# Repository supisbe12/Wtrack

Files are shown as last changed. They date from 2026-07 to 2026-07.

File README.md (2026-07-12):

# Wtrack
Wtrack — a multi-network location tracker device

Wtrack is a tracker with a combination of Apple Find My, Hubble (terrestrial + satellite), GPS, and BLE proximity detection on one barebones PCB (no enclosure) which goes inside your wallet.
I want it to be barebone because I wanted to be able to see the actual PCB because it looks cool ,But I am planning to add a layer acrylic spray that I already have available to prevent water from affecting the board.

---
Schematic



PCB



3D view



Battery Cap



---
Bill Of Materials: https://docs.google.com/spreadsheets/d/1D9NDHI8oiGVwoLBUYLz9mFe_7Vkk39w_oN8q6zxxxLU/edit?usp=sharing

Bill of materials (CSV): https://github.com/supisbe12/Wtrack/blob/main/BOM.csv

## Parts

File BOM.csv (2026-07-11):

Reference | Qty | Value | DNP | Exclude from BOM | Exclude from Board | Footprint | Datasheet
B1 | 1 | CR2032-BS-6-1 |  |  |  | easyeda:BAT-TH_CR2032-BS-6-1 | https://lcsc.com/product-detail/Battery-Holders-Clips-Contacts_Button-battery-holder-CR2032_C70377.html
C1,C2 | 2 | 12pF NP0 ±2%, 0402 |  |  |  | easyeda:C0402 | https://lcsc.com/product-detail/Multilayer-Ceramic-Capacitors-MLCC-SMD-SMT_12pF-120-5-50V_C1547.html
C3 | 1 | 0.3pF |  |  |  | easyeda:C0201 | https://lcsc.com/product-detail/Multilayer-Ceramic-Capacitors-MLCC-SMD-SMT_muRata_GRM0335C1ER30BA01D_0-3pF-R30-0-1pF-25V_C88909.html
C4 | 1 | 1.0pF NP0 ±5%, 0402 |  |  |  | easyeda:C0402 | https://lcsc.com/product-detail/Multilayer-Ceramic-Capacitors-MLCC-SMD-SMT_100pF-101-5-50V_C1546.html
C5 | 1 | 100nF X7R ±10%, 0402 |  |  |  | easyeda:C0402 | https://lcsc.com/product-detail/Multilayer-Ceramic-Capacitors-MLCC-SMD-SMT_SAMSUNG_CL05B104KO5NNNC_100nF-104-10-16V_C1525.html
C6 | 1 | 4.7uF X7R ±10%, 0603 |  |  |  | Capacitor_SMD:C_0603_1608Metric | https://search.murata.co.jp/Ceramy/image/img/A01X/G101/ENG/GRM188Z71A475KE15-01A.pdf
C7,C8,C12 | 3 | 100pF NP0 ±5%, 0402 |  |  |  | easyeda:C0402 | https://lcsc.com/product-detail/Multilayer-Ceramic-Capacitors-MLCC-SMD-SMT_100pF-101-5-50V_C1546.html
C9 | 1 | 820pF NP0 ±5%, 0402 |  |  |  | easyeda:C0402 | https://lcsc.com/product-detail/Multilayer-Ceramic-Capacitors-MLCC-SMD-SMT_SAMSUNG_CL05B104KO5NNNC_100nF-104-10-16V_C1525.html
C10 | 1 | KR-5R5C155-R |  |  |  | KR5R5C155R | https://componentsearchengine.com/Datasheets/2/KR-5R5C155-R.pdf
C14,C15 | 2 | 1.0µF X7R ±10%, 0603 |  |  |  | Capacitor_SMD:C_0603_1608Metric | https://search.murata.co.jp/Ceramy/image/img/A01X/G101/ENG/GRM188Z71A475KE15-01A.pdf
C16 | 1 | 4.7nF X7R ±10% |  |  |  | easyeda:C0402 | https://lcsc.com/product-detail/Multilayer-Ceramic-Capacitors-MLCC-SMD-SMT_SAMSUNG_CL05B104KO5NNNC_100nF-104-10-16V_C1525.html
C19 | 1 | 10uF |  |  |  | easyeda:C0603 | https://lcsc.com/product-detail/Multilayer-Ceramic-Capacitors-MLCC-SMD-SMT_SAMSUNG_CL10A106KP8NNNC_10uF-106-10-10V_C19702.html
FL1 | 1 | 2450LP14A100T |  |  |  | easyeda:FILTER-SMD_0603-6P-L1.6-W0.8_2450LP14A100T | https://www.lcsc.com/datasheet/C3155782.pdf
IC1 | 1 | RFX2401C |  |  |  | QFN50P300X300X60-17N-D
L1 | 1 | 4.7nH ±5%, 0402 |  |  |  | easyeda:L0402 | https://lcsc.com/product-detail/Inductors-SMD_muRata_LQP15MN4N7B02D_4-7nH-0-1nH_C23769.html
L2 | 1 | 10µH, IDC≥50mA, 0603 |  |  |  | easyeda:L0603 | https://lcsc.com/product-detail/Inductors-SMD_10uH-10_C1035.html
L3 | 1 | 47nH |  |  |  | easyeda:L0402 | https://lcsc.com/product-detail/Inductors-SMD_muRata_LQW15AN47NG00D_LQW15AN47NG00D_C22334.html
L4 | 1 | 10µH, IDC≥80mA, 0603 |  |  |  | easyeda:L0603 | https://lcsc.com/product-detail/Inductors-SMD_10uH-10_C1035.html
L5 | 1 | 3.9nH ±5%, 0402 |  |  |  | easyeda:L0402 | https://lcsc.com/product-detail/Inductors-SMD_muRata_LQG15HS2N2S02D_2-2nH-0-3nH_C86061.html
L7 | 1 | Bluetooth Antenna |  |  |  | easyeda:ANT-SMD_3P-L3.1-W1.6_ANT3216A063R2400A | https://lcsc.com/product-detail/New-Arrivals_YAGEO-ANT3216A063R2400A_C412135.html
R1 | 1 | 100Ω |  |  |  | Resistor_SMD:R_0402_1005Metric
SC2 | 1 | 3F,2.7V |  |  |  | Capacitor_THT:CP_Radial_D10.0mm_P5.00mm
U1 | 1 | GPS |  |  |  | easyeda:ANT-SMD_L10.0-W3.0 | https://lcsc.com/product-detail/Others_Rainsun-microwave-Tech-GPS1003_C239243.html
U2 | 1 | ATGM336H-5N31 |  |  |  | easyeda:GPSM-SMD_ATGM336H-TR | https://lcsc.com/product-detail/GSM-GPRS-GPS-Modules_ATGM336H-5N-3X_C90770.html
U4 | 1 | NRF52840-QIAA-R |  |  |  | easyeda:AQFN-73_L7.0-W7.0-P0.50-BL-EP4.8 | https://lcsc.com/product-detail/Others_Nordic-Semicon_NRF52840-QIAA-R_Nordic-Semicon-NRF52840-QIAA-R_C190794.html
X1 | 1 | NX2016SA-32MHZ-STD-CZS-5 |  |  |  | easyeda:OSC-SMD_4P-L2.0-W1.6-BL | https://www.lcsc.com/datasheet/C843260.pdf

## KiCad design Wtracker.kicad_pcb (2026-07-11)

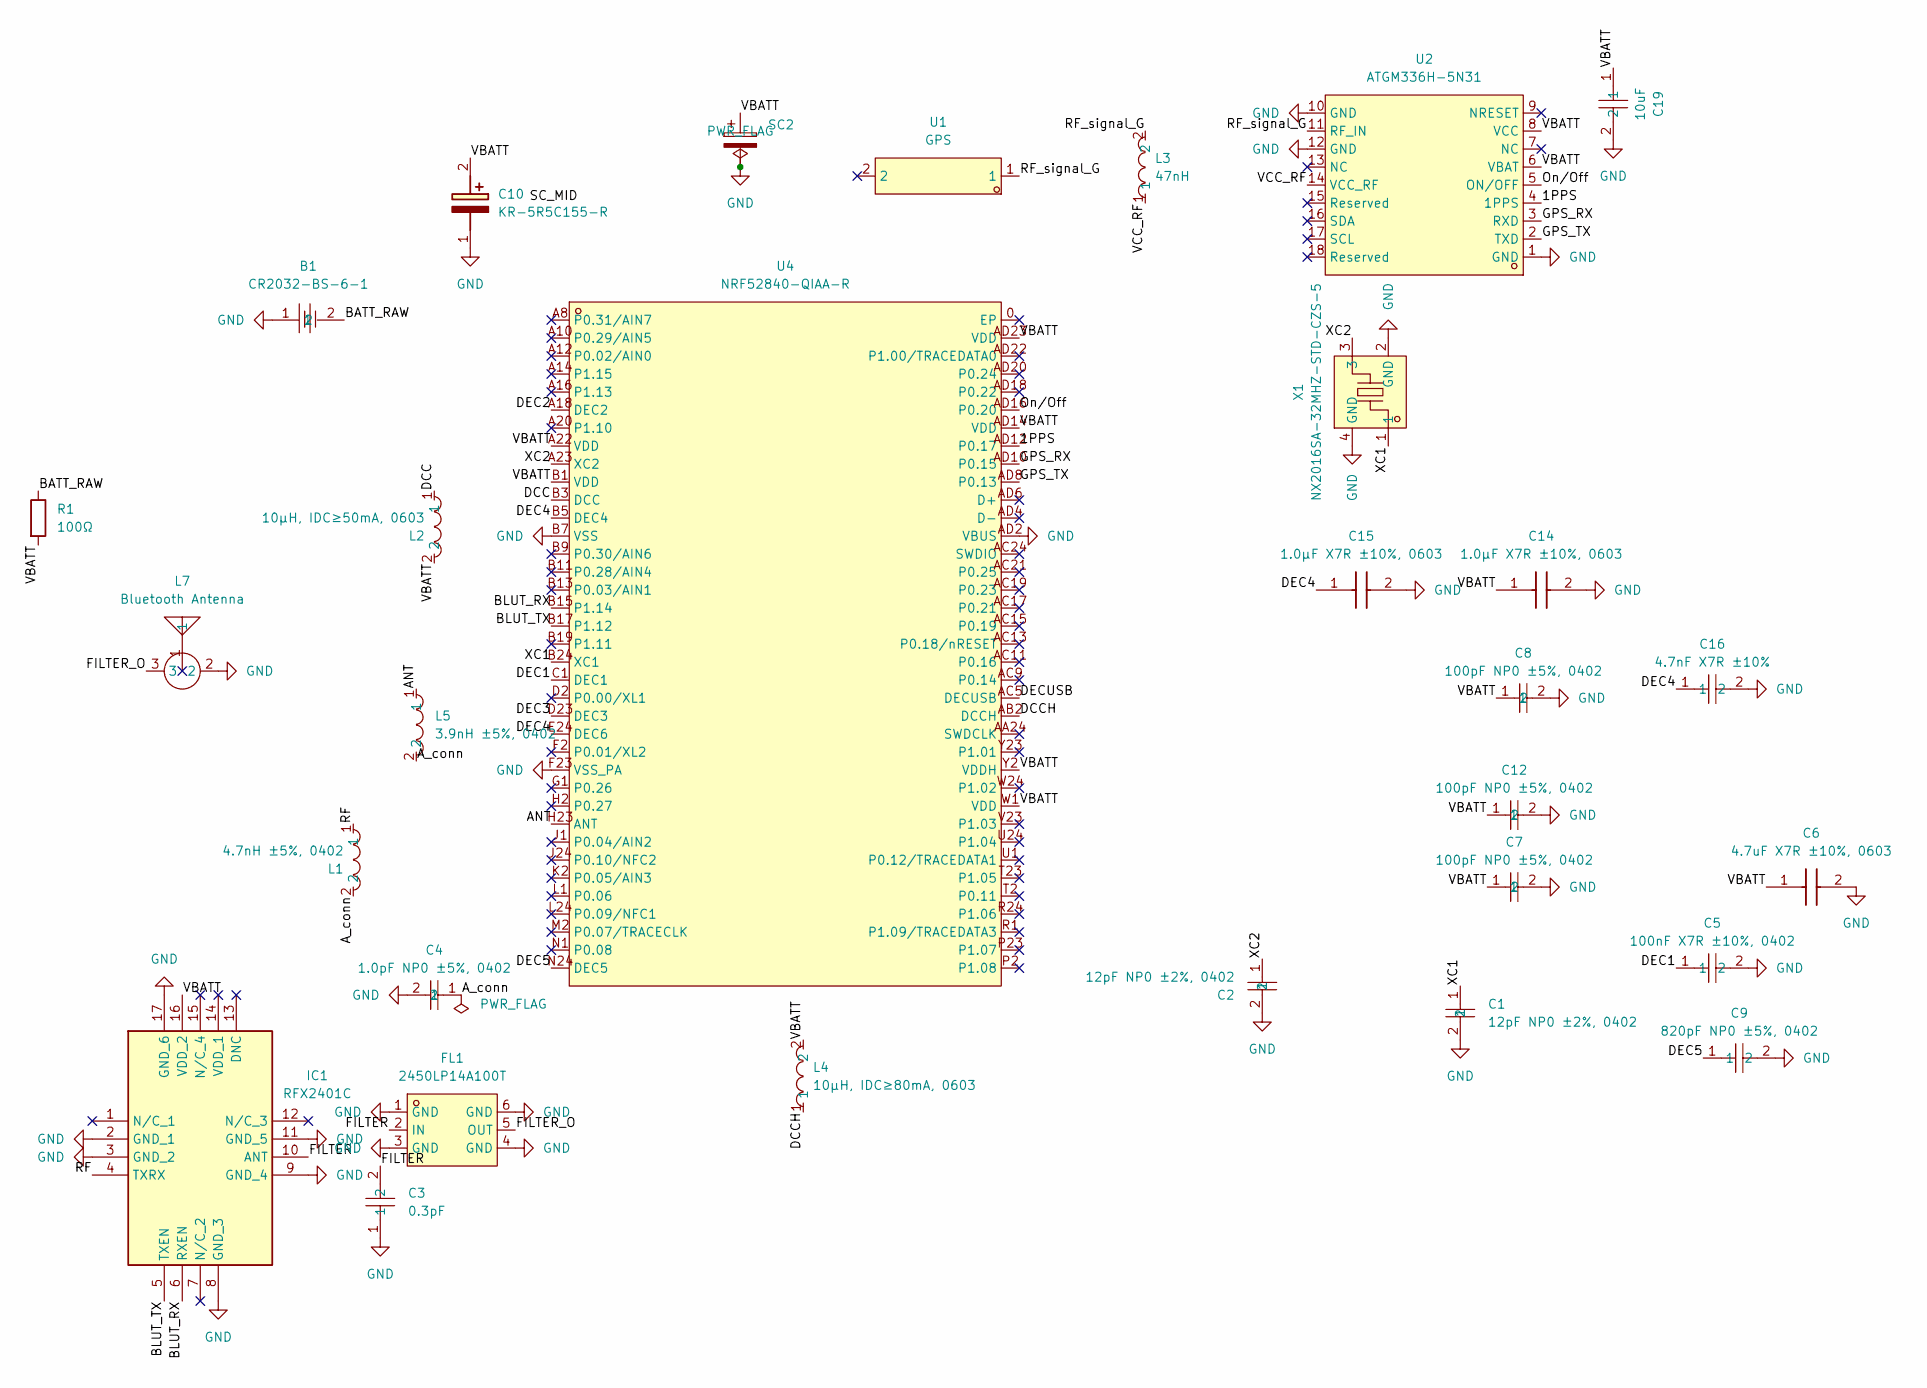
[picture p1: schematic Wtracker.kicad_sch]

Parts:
B1: CR2032-BS-6-1; BAT-TH_CR2032-BS-6-1; MPN CR2032-BS-6-1; LCSC Part C70377
C1, C2: 12pF NP0 ±2%, 0402; C0402; MPN 0402CG120J500NT; LCSC Part C1547
C3: 0.3pF; C0201; MPN GRM0335C1ER30BA01D; LCSC Part C88909
C4: 1.0pF NP0 ±5%, 0402; C0402; MPN 0402CG101J500NT; LCSC Part C1546
C5: 100nF X7R ±10%, 0402; C0402; MPN CL05B104KO5NNNC; LCSC Part C1525
C6: 4.7uF X7R ±10%, 0603; C_0603_1608Metric; Mouser Part Number 81-GRM188Z71A475KE5D
C7, C8, C12: 100pF NP0 ±5%, 0402; C0402; MPN 0402CG101J500NT; LCSC Part C1546
C9: 820pF NP0 ±5%, 0402; C0402; MPN CL05B104KO5NNNC; LCSC Part C1525
C10: KR-5R5C155-R; KR5R5C155R; Mouser Part Number 504-KR-5R5C155-R
C14, C15: 1.0µF X7R ±10%, 0603; C_0603_1608Metric; Mouser Part Number 81-GRM188Z71A475KE5D
C16: 4.7nF X7R ±10%; C0402; MPN CL05B104KO5NNNC; LCSC Part C1525
C19: 10uF; C0603; MPN CL10A106KP8NNNC; LCSC Part C19702
FL1: 2450LP14A100T; FILTER-SMD_0603-6P-L1.6-W0.8_2450LP14A100T; MPN 2450LP14A100T; LCSC Part C3155782
IC1: RFX2401C; QFN50P300X300X60-17N-D; Mouser Part Number 477-RFX2401C
L1: 4.7nH ±5%, 0402; L0402; MPN LQP15MN4N7B02D; LCSC Part C23769
L2: 10µH, IDC≥50mA, 0603; L0603; MPN SDFL1608S100KTF; LCSC Part C1035
L3: 47nH; L0402; MPN LQW15AN47NG00D; LCSC Part C22334
L4: 10µH, IDC≥80mA, 0603; L0603; MPN SDFL1608S100KTF; LCSC Part C1035
L5: 3.9nH ±5%, 0402; L0402; MPN LQG15HS2N2S02D; LCSC Part C86061
L7: Bluetooth Antenna; ANT-SMD_3P-L3.1-W1.6_ANT3216A063R2400A; MPN ANT3216A063R2400A; LCSC Part C412135
R1: 100Ω; R_0402_1005Metric
SC2: 3F,2.7V; CP_Radial_D10.0mm_P5.00mm
U1: GPS; ANT-SMD_L10.0-W3.0; MPN GPS1003; LCSC Part C239243
U2: ATGM336H-5N31; GPSM-SMD_ATGM336H-TR; MPN ATGM336H-5N31; LCSC Part C90770
U4: NRF52840-QIAA-R; AQFN-73_L7.0-W7.0-P0.50-BL-EP4.8; MPN NRF52840-QIAA-R; LCSC Part C190794
X1: NX2016SA-32MHZ-STD-CZS-5; OSC-SMD_4P-L2.0-W1.6-BL; MPN NX2016SA-32MHZ-STD-CZS-5; LCSC Part C843260

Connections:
/1PPS: U2.4 (1PPS), U4.AD12 (P0.17)
/ANT: L5.1, U4.H23 (ANT)
/A_conn: C4.1, L1.2, L5.2
/BATT_RAW: B1.2, R1.1
/BLUT_RX: IC1.6 (RXEN), U4.B15 (P1.14)
/BLUT_TX: IC1.5 (TXEN), U4.B17 (P1.12)
/DCC: L2.1, U4.B3 (DCC)
/DCCH: L4.1, U4.AB2 (DCCH)
/DEC1: C5.1, U4.C1 (DEC1)
/DEC2: U4.A18 (DEC2)
/DEC3: U4.D23 (DEC3)
/DEC4: C15.1, C16.1, U4.B5 (DEC4), U4.E24 (DEC6)
/DEC5: C9.1, U4.N24 (DEC5)
/DECUSB: U4.AC5 (DECUSB)
/FILTER: C3.2, FL1.2 (IN), IC1.10 (ANT)
/FILTER_O: FL1.5 (OUT), L7.3
/GPS_RX: U2.3 (RXD), U4.AD10 (P0.15)
/GPS_TX: U2.2 (TXD), U4.AD8 (P0.13)
/On/Off: U2.5 (ON/OFF), U4.AD16 (P0.20)
/RF: IC1.4 (TXRX), L1.1
/RF_signal_G: L3.2, U1.1 (1_1), U2.11 (RF_IN)
/VBATT: C6.1, C7.1, C8.1, C10.2 (+), C12.1, C14.1, C19.1, IC1.16 (VDD_2), L2.2, L4.2, R1.2, SC2.1, U2.6 (VBAT), U2.8 (VCC), U4.A22 (VDD), U4.AD14 (VDD), U4.AD23 (VDD), U4.B1 (VDD), U4.W1 (VDD), U4.Y2 (VDDH)
/VCC_RF: L3.1, U2.14 (VCC_RF)
/XC1: C1.1, U4.B24 (XC1), X1.1
/XC2: C2.1, U4.A23 (XC2), X1.3
GND: B1.1, C1.2, C2.2, C3.1, C4.2, C5.2, C6.2, C7.2, C8.2, C9.2, C10.1 (-), C12.2, C14.2, C15.2, C16.2, C19.2, FL1.1 (GND), FL1.3 (GND), FL1.4 (GND), FL1.6 (GND), IC1.2 (GND_1), IC1.3 (GND_2), IC1.8 (GND_3), IC1.9 (GND_4), IC1.11 (GND_5), IC1.17 (GND_6), L7.2, SC2.2, U2.1 (GND), U2.10 (GND), U2.12 (GND), U4.AD2 (VBUS), U4.B7 (VSS), U4.F23 (VSS_PA), X1.2 (GND), X1.4 (GND)

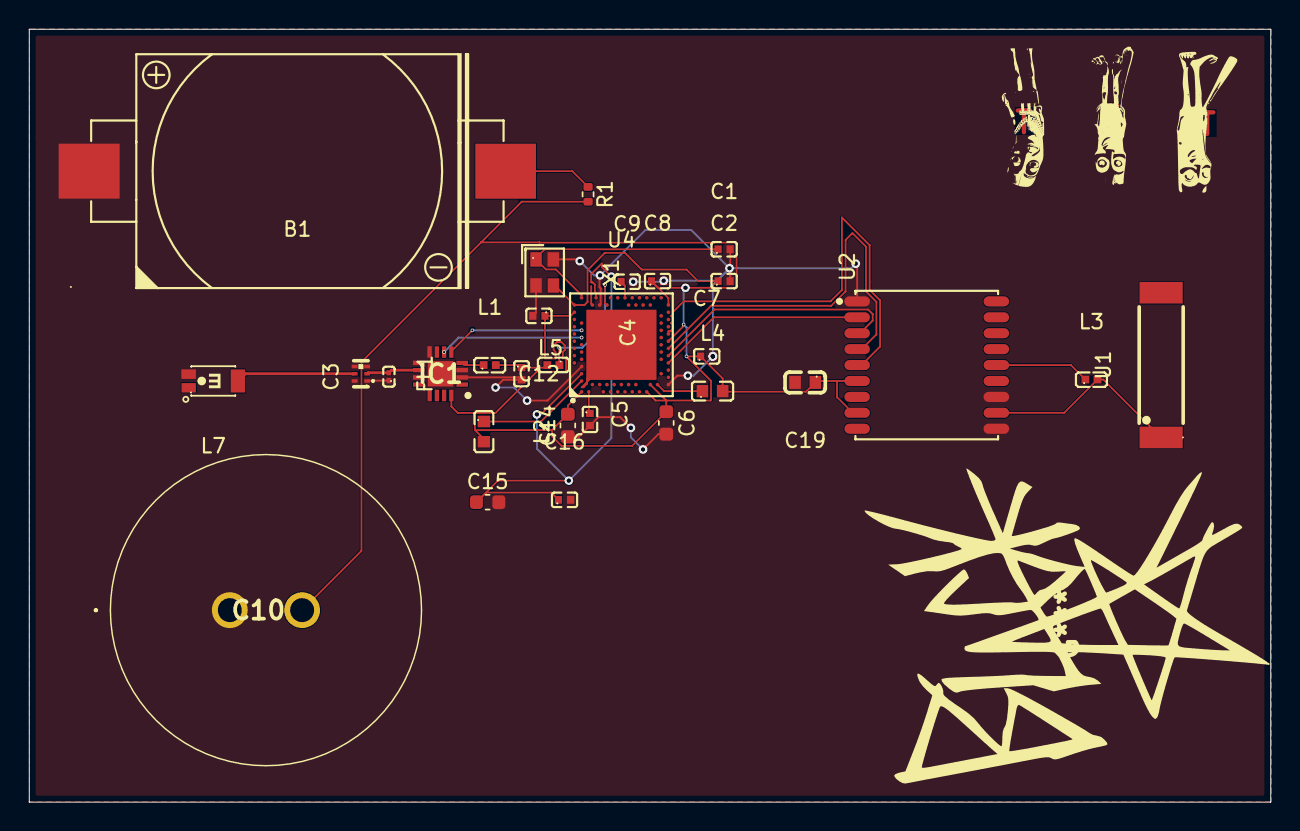
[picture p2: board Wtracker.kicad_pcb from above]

Board: 2 copper layers, 85.8 x 53.4 mm, 32 parts (0 on the bottom side), 23 nets.

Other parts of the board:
T: LOGO
T#2, T#3: LOGO

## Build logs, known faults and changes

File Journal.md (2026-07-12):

# Total time : 25 hours
**_Day 1_** - Searched for parts to plan out the schematic for this project - **5 hours**

I spent a lot of time to find out the exact footprints that I needed for each part of the schematic like capacitors, inductors, and antennas and many of the other parts.
It was difficult because I had to choose the exact needs of every part by using the datasheets.
I also spent a lot of time trying to figure out the problem that I had with importing symbol and footprints straight for LSCS or JLPCB using the ImpartGUI. This part took me like 2 hours and afterwards I asked a friend to help me and he introduced me to another plugin that allowed me to do
the same thing and it actually worked this time.



**_Day 2_** - Searched for Datasheets to connect schematics together - **7 hours**

Learned a lot about datasheets today and how to read them. It was really hard to figure out what some of the labels meant but google explained it well



Then I learned how to connect Antennas together and it was quite complicated with the usage of a lot of back and forth of capacitors and inductors which I didn't understand why then I researched it. which is required because to match the frequency.
Also learned that Antennas sometimes have different modes like active and passive.



Also got the board wrong yesterday so had to find a new one.



Schematic kinda messy gonna organize it tommorrow.

**_Day 3_** - Set up Kicad and easy EDA on my computer and finished schematics- **2 hours**

It took me a long time to setup kicad and all of the imports and file path right but when I finally got it working I was able to finish connecting the bluetooth harmonic filter and everything on that track.



It is still very messy I am going to clean it up soon when i get motivation.

**_Day 4_** - Fixed Footprints, Started PCB and wiring- **6 hours**

I had to add my old footprints which was on my computer and moved it on over to my laptop So I had to refind the footprint for some of the older parts that I placed.



After that, I was organizing the location of the hardware until I found it really hard to wire the NRF52840-QIAA-R because of it's extremely small pads.



It wasn't fitting the JLPCB standard and I decided to stop for the day and ask for help on slack and try again tomorrow.
I learned about some new stuff like impedance and stub routing/trace and new constraints that JLPCB have.

**_Day 5_** - Finished PCB- **5 hours**
I explored more options for JLPCB production and decided to use the smallest possible Vias that is allowed by JLPCB to wire the NRF. After that I just finished wiring everything based on my schematic while i did get a little confused at some point but it was pretty smooth sailing.

I learned a lot about the placements of antennas and everything and how they needed to be seperated and different copper

**_Day 6_** - Finished PCB- **2 hours**
Changed the PCB and researched a thinner and stronger capacitor to fit the thin look i'm looking for. updated schematic and BOM for review



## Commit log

2026-07-04 Force remove .history from tracking
    [Wtracker.kicad_pcb, Wtracker.kicad_sch]
2026-07-05 worked on antenna of pcb
    [GPSmod.kicad_sch, Wtracker.kicad_sch]
2026-07-05 added the GPS and finished Bluetooth antennas
    [GPSmod.kicad_sch, Wtracker.kicad_sch]
2026-07-05 Add journal entries for project progress
    Documented progress on project schematics and datasheets over two days, including challenges faced and solutions found.
2026-07-08 Revise journal with new entries and images
    Updated journal entries with new learnings about antennas, Kicad setup, and PCB design challenges. Added images and organized content for clarity.
2026-07-09 updated pcb and schematic
    [Wtracker.csv, Wtracker.kicad_pcb, Wtracker.kicad_sch]
2026-07-09 Add Bill Of Materials link to README
    Updated the README to include a link to the Bill Of Materials.
2026-07-11 Replace images in README.md
    Updated images in the README for schematic and PCB sections.
2026-07-11 updated pcb and schematic and BOM
    [BOM.csv, Wtracker.kicad_pcb, Wtracker.kicad_sch]
2026-07-11 Add Day 6 entry with PCB updates and BOM changes
    Updated the journal with Day 6 details about PCB changes and capacitor research.
2026-07-11 Update README to include BOM.csv link
    Added link to BOM.csv in the README.
2026-07-11 Update BOM link format in README
2026-07-11 the goat
    [Wtracker.kicad_pcb, Wtracker.kicad_sch]
2026-07-12 updated pcb and cad
2026-07-12 update pcb and added CAD
